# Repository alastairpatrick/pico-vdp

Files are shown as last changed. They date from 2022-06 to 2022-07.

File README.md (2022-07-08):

# Pico-VDP RC2014 Board

In a nutshell, this project is a 39-pin RC2014 compatible multimedia board and associated software, providing video output, audio output, keyboard input, mouse input and [RomWBW](https://github.com/wwarthen/RomWBW) driver for Z80 retro computers. At the time of writing, it has been tested only with the [SC126 computer](https://smallcomputercentral.wordpress.com/sc126-z180-motherboard-rc2014/) but should work with others.

A goal is to emulate hardware that could, in an alternate history, have been implemented for an 8-bit home micro circa 1985. The design does not represent the state-of-the-art for that period. For example, the Commodore Amiga 1000 computer, released in 1985, was much more capable. Rather, the design is intended to not only be possible in 1985 but cost-effective enough to put in an 8-bit home computer. For that reason, the VDP9938 graphics chip, used by MSX2 computers, is the main inspiration.

Another goal is for the design to have era-reminiscent "quirks," which might be cleverly exploited to improve performance and/or capabilities. Some of these will intentionally remain undocumented, even if I take time to write documentation.

A Raspberry Pi Pico microcontroller board, not to be confused with the Raspberry Pi computer, provides the "brains." It was chosen because it provides a cheap way to host USB devices and generate a VGA video signal, because it is DIY soldering friendly and because it doesn't require special hardware to program - just a regular USB cable.

The reason for not emulating actual 1985 vintage hardware, such as the VDP9938 chip, is because I'm doing this primarily for my own entertainment.

The schematic and PCB layout files are for DesignSpark PCB.

## Current Status

These are the features supported by the revision 1 hardware and associated software at the time of writing. This is a work in progress. Expect the hardware, both actual and emulated, and the software to break backwards compatibility as work progresses.

- Graphics
  - VGA connector
  - 192KB VRAM
    - 2x 32KB double-buffered Display RAM banks
    - 128KB Blitter RAM
  - Bitmap modes
    - 256x192 pixels @ 2/4/16 colors
    - 512x192 pixels @ 2/4 colors
  - 1 hardware cursor
  - Hardware assisted horizontal & vertical scrolling
  - VDP9938 inspired blitter coprocessor
  - Amstrad PCW inspired "roller RAM"
  - Commodore Amiga inspired "screens"
  - Blitter command FIFO
    - inspired by modern GPUs
    - backed by blitter RAM
    - facilitates parallelism between CPU and VDP
  -  16 cycle accurate emulation
  - RomWBW driver
    - 42x24 text, 16 colors
    - 64x24 text, 4 colors
    - 80x24 text, 4 colors
- Audio
  - PCB mount speaker
  - 2x emulated AY-891x programmable sound generators
    - 6 tone channels
    - 2 noise channels
    - 2 envelopes
  - 16 cycle accurate emulation
- USB
  - Hub supported
  - Keyboard
    - MSX International keyboard matrix
    - Programmable IO controls keyboard LED
  - Mouse
    - 8-bit X, 8-bit Y, button state
- Software
  - RP2040 firmware
  - RomWBW HBIOS drivers
  - RomWBW TUNE.COM plays AY-891x chip tunes
- Microcontroller over-clocking
  - Over-clocking not needed if audio disabled
  - 195MHz over-clock needed for video & audio

## Contemplated Future Projects

- Revision 2 board
  - Reduce board height, increase PCB area
  - Line level mono audio output instead of PCB mounted speaker
  - Mount Raspberry Pi Pico with castellated through holes rather than headers
  - Increase space between USB port and VGA port
  - Change address decoding logic to locate AY-891x IO ports at same addresses as a popular board
  - Optional enhanced RC2014 header pins
    - For mechanical support only 
    - Keep full support for 39/40 pin unenhanced RC2014 connection
  - Remove UART support
  - Remove mute header
- Single board computer utilizing the Pico-VDP
- FUZIX driver
- Video display processor SDK
  - for writing interactive bitmap graphics applications in assembly language and/or C
- BASIC interpreter with bitmap graphics modes & commands
  - CP/M and/or FUZIX
- Documentation
  - Hardware Manuals
  - SDK Reference
- Integrate HBIOS and FUZIX drivers into respective source repositories
- 256 color mode
- Image viewer program
- Port a game

## AY-891x Accuracy

Hello AY-3-8910 aficionado! Unfortunately the AY emulator only emulates every 16th cycle, i.e. the emulator is not cycle accurate. Another difference is, unlike the original chips, this uses pulse width modulation.
Unlike some AY emulators, this one is quite constrained by the performance of the $1 microcontroller it runs on, which also emulates a video display processor in parallel.
I tried some existing AY emulators but none were fast enough. That's why I wrote a new one, which trades off accuracy for performance.
Making the emulation sound more like the original chips is desirable and hopefully it can be improved but making it sound exactly like the original chips is not a goal.

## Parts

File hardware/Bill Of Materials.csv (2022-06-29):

Report Written: | Wednesday, June 29, 2022
Design Path: | D:\src\pico-vdp\hardware\pico-vdp.pcb
Design Title:
Created: | 4/14/2022 3:50:07 PM
Last Saved: | 5/4/2022 10:54:51 AM
Editing Time: | 26617 min
Units: | thou (precision 0)
Bill of Materials generated with DesignSpark PCB - www.DesignSpark.com/pcb
--------------------------------------------------------------------------
Ref Name | Qty | Component | Value | Package | Manufacturer | MPN | RS Part Number | Other Part Number | Description
U5 | 1 | 74AHC32 |  | DIL |  |  |  |  | 2IPNOR
U1 | 1 | 74AHC138 |  | DIL |  |  |  |  | 3TO8DECODER
U3 | 1 | 74AHC138 |  | DIL |  |  |  |  | 3TO8DECODER
U4 | 1 | 74LVC245A |  | DIL |  |  |  |  | OCTALBUSTX
C1 | 1 | C |  | RADIAL1 |  |  |  |  | Capacitor
C7 | 1 | C |  | RADIAL1 |  |  |  |  | Capacitor
C5 | 1 | C |  | RADIAL1 |  |  |  |  | Capacitor
C3 | 1 | C | 4.7pF | RADIAL1 |  |  |  |  | Capacitor
C6 | 1 | C | 100nF | RADIAL1 |  |  |  |  | Capacitor
C2 | 1 | C_ELECTRO | 4.7uF | CAPP1V |  |  |  |  | Capacitor
C4 | 1 | C_ELECTRO | 10uF | CAPP1V |  |  |  |  | Capacitor
PL3 | 1 | HEADER_RC2014 |  | DSC |  |  |  |  | 39-pin right angle haeader
PL1 | 1 | HEADER_S6 |  | DSC |  |  |  |  | 6-pin header
PL2 | 1 | HEADER_S9 |  | DSC |  |  |  |  | 9-pin header
CONN1 | 1 | ICD15S13E4GX00LF |  | ICD15S13E4GX00LF | Amphenol | ICD15S13E4GX00LF |  |  | 15-pin D-Sub Connector
J5 | 1 | JUMPER_2 |  | DSC |  |  |  |  | 2 way Pin Header
J4 | 1 | JUMPER_2 |  | DSC |  |  |  |  | 2 way Pin Header
J2 | 1 | JUMPER_2 |  | DSC |  |  |  |  | 2 way Pin Header
J3 | 1 | JUMPER_2 |  | DSC |  |  |  |  | 2 way Pin Header
J1 | 1 | JUMPER_2 |  | DSC |  |  |  |  | 2 way Pin Header
U2 | 1 | NJM2113D |  | DIP762W56P254L880H425Q8N | New Japan Radio | NJM2113D |  |  | Low Voltage Audio Amplifier
LS1 | 1 | PCB_SPEAKER |  | AST02308MRR | PUI Audio | AST-02308MR-R |  |  | Speaker
R12 | 1 | R | 1K | DSC |  |  |  |  | Resistor
R10 | 1 | R | 1K | DSC |  |  |  |  | Resistor
R15 | 1 | R | 1K | DSC |  |  |  |  | Resistor
R16 | 1 | R | 2K2 | DSC |  |  |  |  | Resistor
R13 | 1 | R | 2K2 | DSC |  |  |  |  | Resistor
R7 | 1 | R | 33K | DSC |  |  |  |  | Resistor
R2 | 1 | R | 47K | DSC |  |  |  |  | Resistor
R3 | 1 | R | 47K | DSC |  |  |  |  | Resistor
R1 | 1 | R | 47K | DSC |  |  |  |  | Resistor
R8 | 1 | R | 68K | DSC |  |  |  |  | Resistor
R17 | 1 | R | 100 | DSC |  |  |  |  | Resistor
R18 | 1 | R | 100 | DSC |  |  |  |  | Resistor
R14 | 1 | R | 470 | DSC |  |  |  |  | Resistor
R11 | 1 | R | 470 | DSC |  |  |  |  | Resistor
R9 | 1 | R | 470 | DSC |  |  |  |  | Resistor
R6 | 1 | R | 560 | DSC |  |  |  |  | Resistor
R5 | 1 | R | 560 | DSC |  |  |  |  | Resistor
R4 | 1 | R | 560 | DSC |  |  |  |  | Resistor
U6 | 1 | RP2040 |  | DIL |  |  |  |  | Microcontroller breakout board
D1 | 1 | SCHOTTKY |  | DSC |  | 1N5817 |  |  | Schottky Diode

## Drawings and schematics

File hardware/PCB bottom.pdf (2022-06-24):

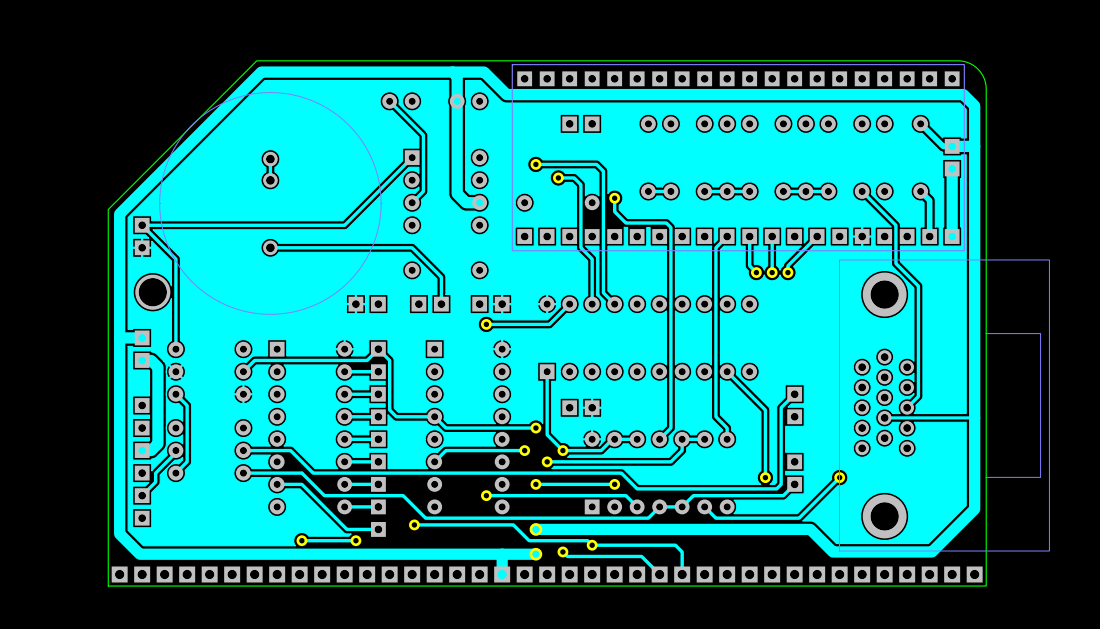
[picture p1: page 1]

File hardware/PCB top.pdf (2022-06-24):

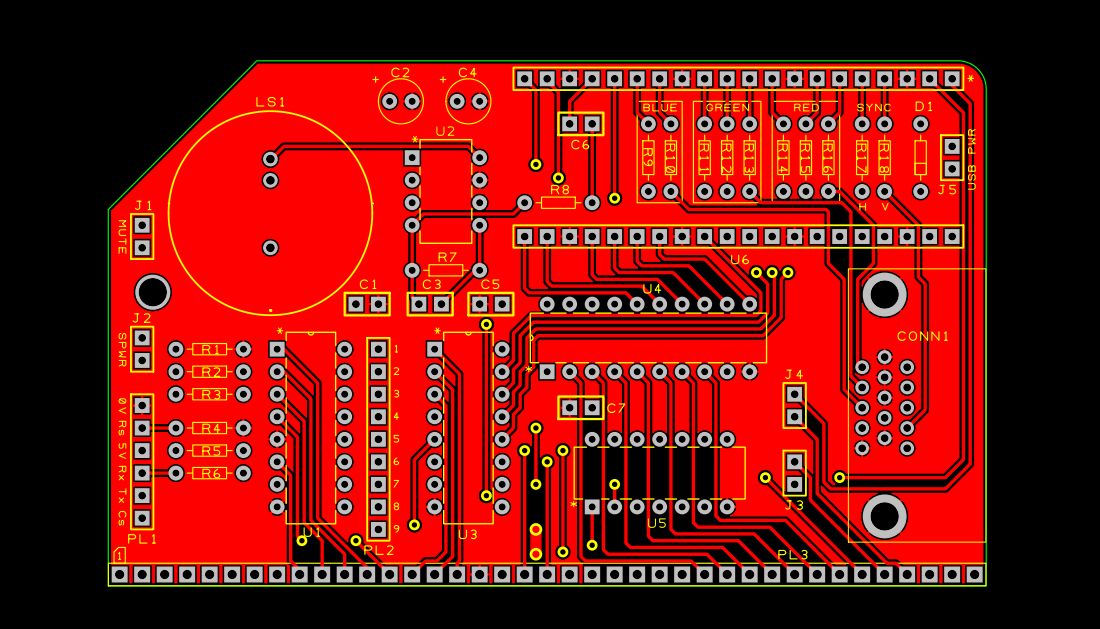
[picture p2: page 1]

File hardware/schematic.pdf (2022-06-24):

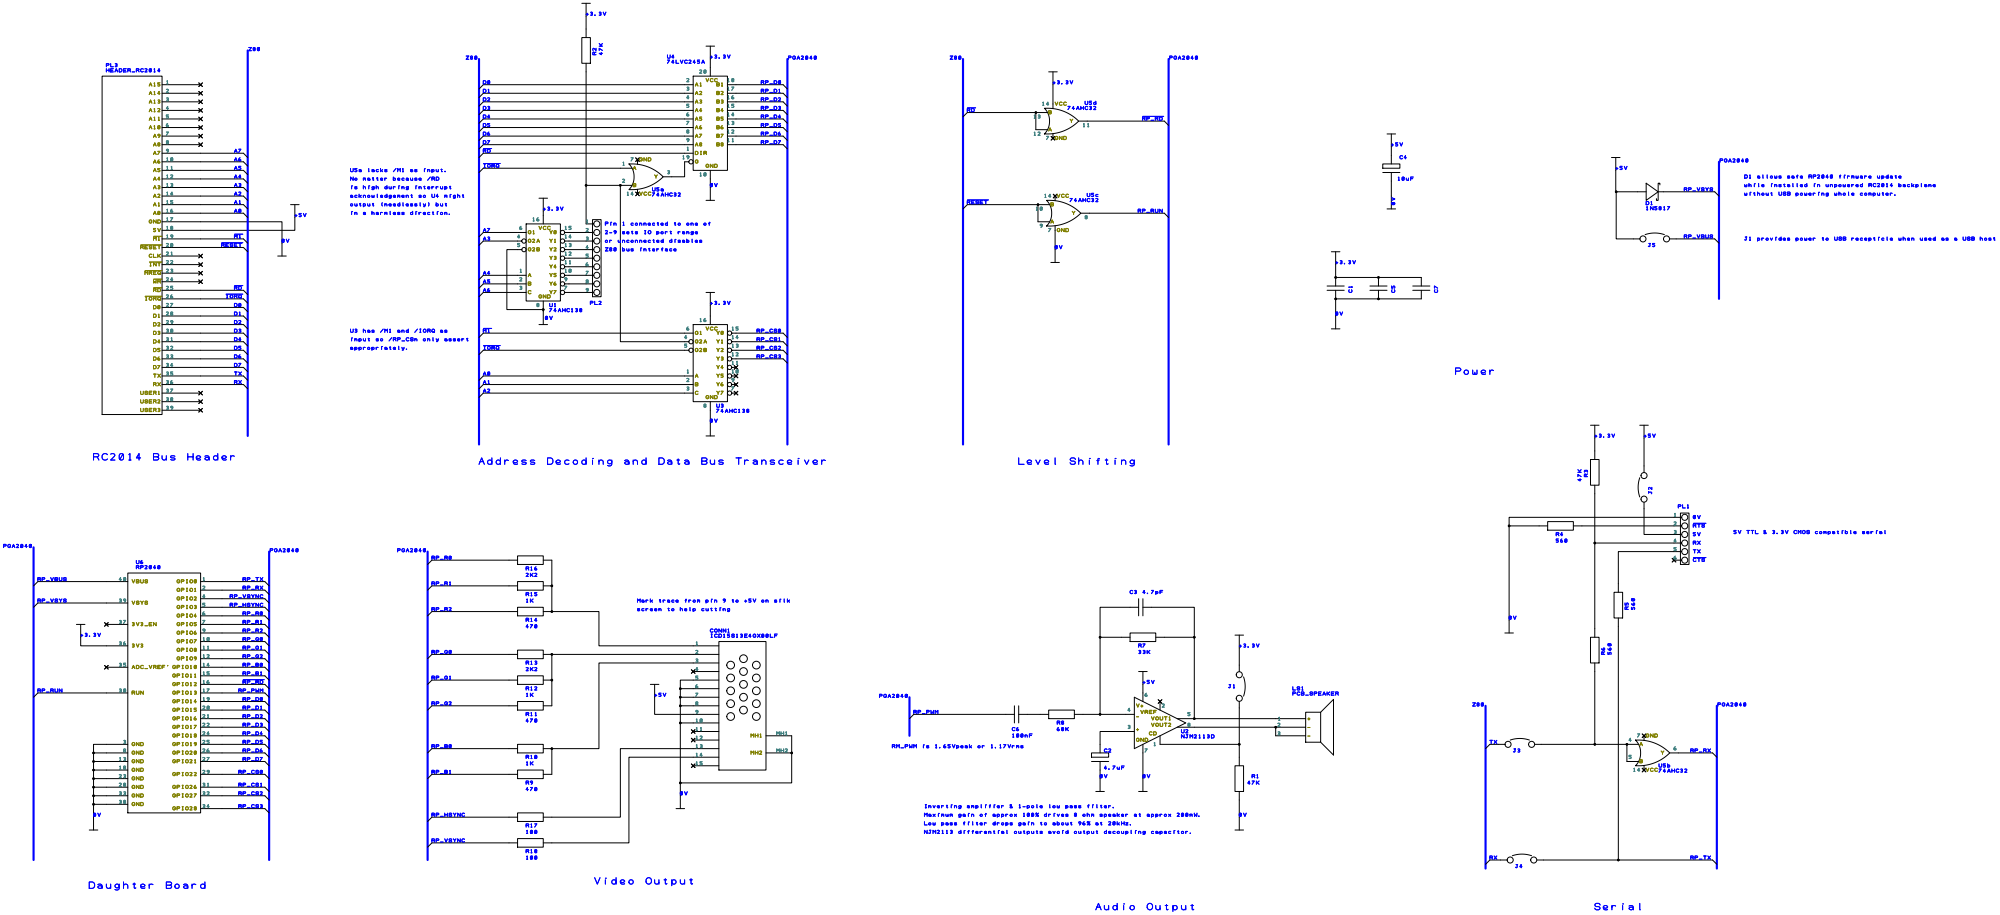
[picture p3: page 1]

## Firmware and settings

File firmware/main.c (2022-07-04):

#include <stdlib.h>
#include <stdio.h>
#include "pico/multicore.h"
#include "pico/stdlib.h"
#include "hardware/adc.h"
#include "hardware/structs/bus_ctrl.h"
#include "hardware/structs/syscfg.h"
#include "tusb.h"

#include "audio.h"
#include "hid.h"
#include "blit.h"
#include "perf.h"
#include "pins.h"
#include "scan_out.h"
#include "section.h"
#include "supply.h"
#include "sys80.h"
#include "video_dma.h"

void ScanMain() {
  InitPerf();
  InitSupplyMonitor();
  tusb_init();

  if (PICOVDP_ENABLE_AUDIO) {
    InitAudio();
  }

  InitVideoInterrupts();
  StartVideo();  

  for (;;) {
    UpdateKeyboard();
    UpdateSupplyMonitor();
    tuh_task();
  }
}

void InitLED() {
  gpio_init(LED_PIN);
  gpio_set_dir(LED_PIN, GPIO_OUT);
}

int main() {
  stdio_init_all();
  adc_init();
  InitPerf();
  InitLED();
  
  InitVideo(&g_timing1024_768);
  SetVideoResolution(1, 2);

  InitSys80();

  if (PICOVDP_ENABLE_AUDIO) {
    InitAudio();
  }

  multicore_launch_core1(ScanMain);
  BlitMain(); 
}

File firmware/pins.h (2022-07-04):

#ifndef PINS_H
#define PINS_H

// Remember .pio files might have pin numbers hard coded.
#define TX_PIN 0
#define RX_PIN 1
#define SYNC_PINS 2
#define VSYNC_PIN (SYNC_PINS+0)
#define HSYNC_PIN (SYNC_PINS+1)
#define VIDEO_PINS 4
#define RED_PINS (VIDEO_PINS+0)
#define GREEN_PINS (VIDEO_PINS+3)
#define BLUE_PINS (VIDEO_PINS+6)
#define RD_PIN 12
#define PWM_PIN 13
#define DATA_PINS 14
#define SUPPLY_PIN 24
#define LED_PIN 25
#define CS0_PIN 22
#define CS1_PIN 26
#define CS2_PIN 27

#endif  // PINS_H

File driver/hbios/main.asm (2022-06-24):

        .ORG    $8000

MAIN:
        CALL    PVDP_INIT

        LD      D, $68
        CALL    PVDP_SET_CURSOR_STYLE

        LD      C, 0
_LOOP1:        
        CALL    PVDP_KEYBOARD_READ
        LD      A, E

        CP      $0D
        JR      Z, _MAIN_SCROLL_FOR

        CP      $09
        JR      Z, _MAIN_SCROLL_BACK

        CP      $F8
        JR      Z, _MAIN_SCROLL_REVERSE

        CP      $F7
        JR      Z, _MAIN_SCROLL_COPY

        CP      $F6
        JR      Z, _MAIN_SCROLL_HOME

        CALL    PVDP_WRITE_CHAR

        LD      A, (_COL)
        LD      E, A
        INC     A
        LD      (_COL), A
        CALL    PVDP_SET_CHAR_COLOR

        JR      _LOOP1

_MAIN_SCROLL_FOR:
        LD      E, 1
        CALL    PVDP_SCROLL
        JR      _LOOP1

_MAIN_SCROLL_BACK:
        LD      E, -1
        CALL    PVDP_SCROLL
        JR      _LOOP1

_MAIN_SCROLL_REVERSE:
        LD      E, $04
        CALL    PVDP_SET_CHAR_ATTR
        JR      _LOOP1
        
_MAIN_SCROLL_COPY:
        LD      DE, 0
        LD      L, 100
        CALL    PVDP_COPY
        JR      _LOOP1
        
_MAIN_SCROLL_HOME:
        LD      DE, 0
        CALL    PVDP_SET_CURSOR_POS
        JR      _LOOP1


_COL:   .DB     0

_DELAY:
        PUSH    AF
        PUSH    BC
        LD      BC, 10000
_DLOOP:
        DEC     BC
        LD      A, B
        OR      C
        JR      NZ, _DLOOP
        POP     BC
        POP     AF
        RET

; Stubs for RomWBW API
CIO_IDLE:
VDA_ADDENT:
TERM_ATTACH:
        RET

TRUE        .EQU  1
FALSE       .EQU  0
TERMENABLE  .EQU  FALSE
USELZSA2    .EQU  TRUE
VDA_FNCNT   .EQU  15

#INCLUDE "pvdp.asm"

FONT6X8:
#IF USELZSA2
#INCLUDE "font6x8c.asm"
#INCLUDE "unlzsa2s.asm"
#ELSE
#INCLUDE "font6x8u.asm"
#ENDIF

.END

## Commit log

2022-04-04 Prototype 80 system bus interface
2022-04-21 DMA controller fields IO requests. Related tests.
2022-04-23 Video & sync GPIOs consistent with new circuit
2022-05-12 Symbols replace #s to id ports.
    [sys80.c]
2022-05-17 Discontiguous Pico /CS pins to match schematic
2022-05-17 Add hardware design
    [pico-vdp - Board Outline.gbr, pico-vdp - Bottom Copper.gbr, pico-vdp - Bottom Silkscreen.gbr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]
2022-05-17 Video DMA control block buffer smaller
2022-05-20 Framewide x_shift & colored border
2022-05-28 HBIOS driver WIP
2022-05-29 HBIOS keyboard driver WIP
2022-05-29 HBIOS driver builds in RomWBW tree
2022-06-10 current_y register
2022-06-10 Fix case of preprocessor directives
2022-06-12 Sys80 regs are 16-bit in memory So CPU can detect changes when DMA controller zeroes high 8-bits
2022-06-12 Fix HBIOS driver
2022-06-14 Decrease audio DMA buffer size Audio IRQ has priority over video
2022-06-17 Remove audio DMA
2022-06-22 HBIOS driver uses LINE_WRAP reg
2022-06-23 Remove sprite blink feature from firmware Add cursor blink to HBIOS driver
2022-06-24 PDFs for PCB and schematic
2022-06-29 Add bill of materials
    [Bill Of Materials.csv]
2022-07-01 Add Pico SDK as submodule
2022-07-02 GenerateAY runtime more consistent between samples
2022-07-04 Blink LED when supply < 4.5V
